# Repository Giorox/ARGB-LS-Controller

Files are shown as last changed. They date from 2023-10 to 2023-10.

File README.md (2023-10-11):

# ARGB-LS-Controller
Circuit diagram, PCB layout and code for an ATTiny85 powered, addressable RGB LED strip controller.

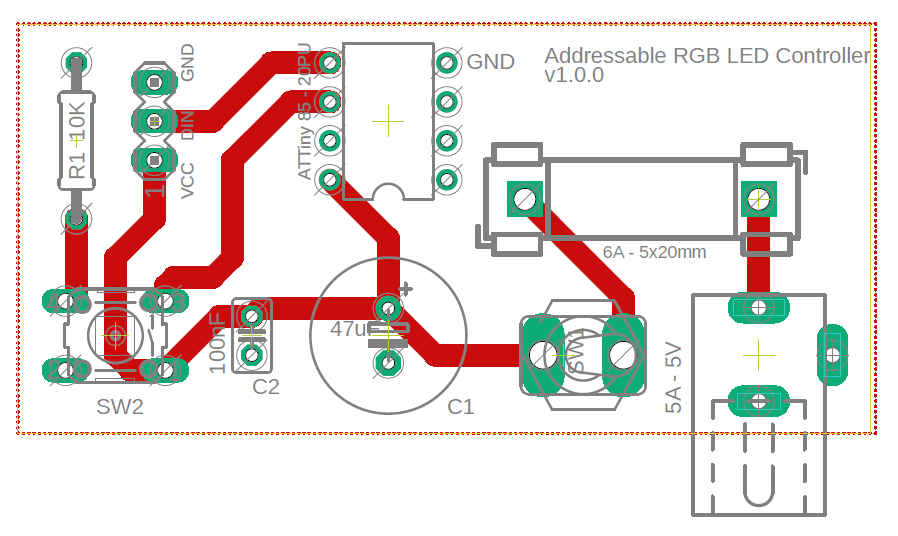
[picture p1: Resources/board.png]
board


# Repository organization

The circuit and board were developed using AutoDesk EAGLE and all files are available in the "Hardware files" folder. Schematic and Board layout PDFs can be found in the "Resources" folder. Controller code can be found in the "Code" folder.

# Project Requirements and Design

The PCB was developed to control any addressable RGB LED strip that uses WS2812B or similar LEDs that take 3 inputs (VCC, GND and Data/DIN) using any DIP8 packaged microcontroller.

All board traces are spec'd to handle up to 5A of current for PCBs fabricated at 1.6mm thickness and 1oz/mm2 allowing for LED strips of up to 88 LED long strips.

Circuit is current-protected up to 6A through a glass fuse at power input and power signal is conditioned using both input capacitors.

R1 is a pull-down resistor for the momentary SW2 push-button that allows for additional inputs to the microcontroller.

The board was developed to handle led-strip control through an ATTiny85 in the DIP8 packaging but should be compatible with all ATTiny microcontrollers in the same outer packaging.

All components are through-hole to reduce cost and facilitate construction.

# Bill of Materials

Besides the board and the led strip:

- 10K ohm resistor (Count: 1)
- 47uF electrolytic capacitor (Count: 1)
- 100nF ceramic capacitor (Count: 1)
- ATTiny85-20PU in DIP8 (Count: 1)
- 6A strand-glass fuse and support (Count: 1)
- Normally-open 4 terminal momentary push-button (Count: 1)
- 5.5mm barrel jack socket (Count: 1)
- SPST switch - Optional (Count: 1)
- DIP8 socket - Optional (Count: 1)

# Quirks

Version 1.0.0 of the board layout/schematic has improper pitch width for the 3 vias used for signal output to the led strip to be used as terminal bars. Pitch between terminals of the fuse are also non-standard, might require customization.

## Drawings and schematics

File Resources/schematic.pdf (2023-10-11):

A

A

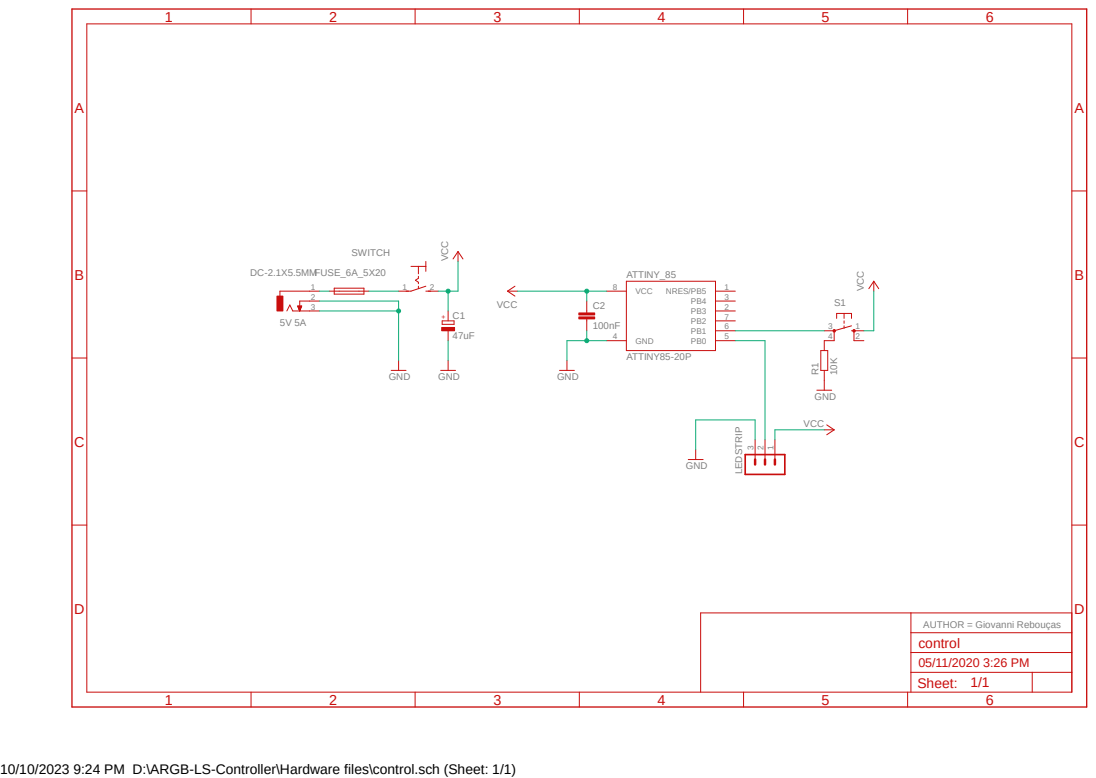
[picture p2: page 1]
GND; ATTINY85-20P; GND¹⁰K; GND VCC; VCC; NRES/PB5; 1 VCC 8; GND 4 ATTINY_85; 1 LEDSTRIP; 1 2 SWITCH; FUSE_6A_5X20

AUTHOR = Giovanni Rebouças
control
Sheet:

10/10/2023 9:24 PM D:\ARGB-LS-Controller\Hardware files\control.sch (Sheet: 1/1)

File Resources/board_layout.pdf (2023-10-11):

6A - 5x20mm R¹ | ATTiny 85 ⁻ 20PU
SW2 | SW¹ ¹⁰K | 100nF | 47uF | 5A ⁻ ⁵V

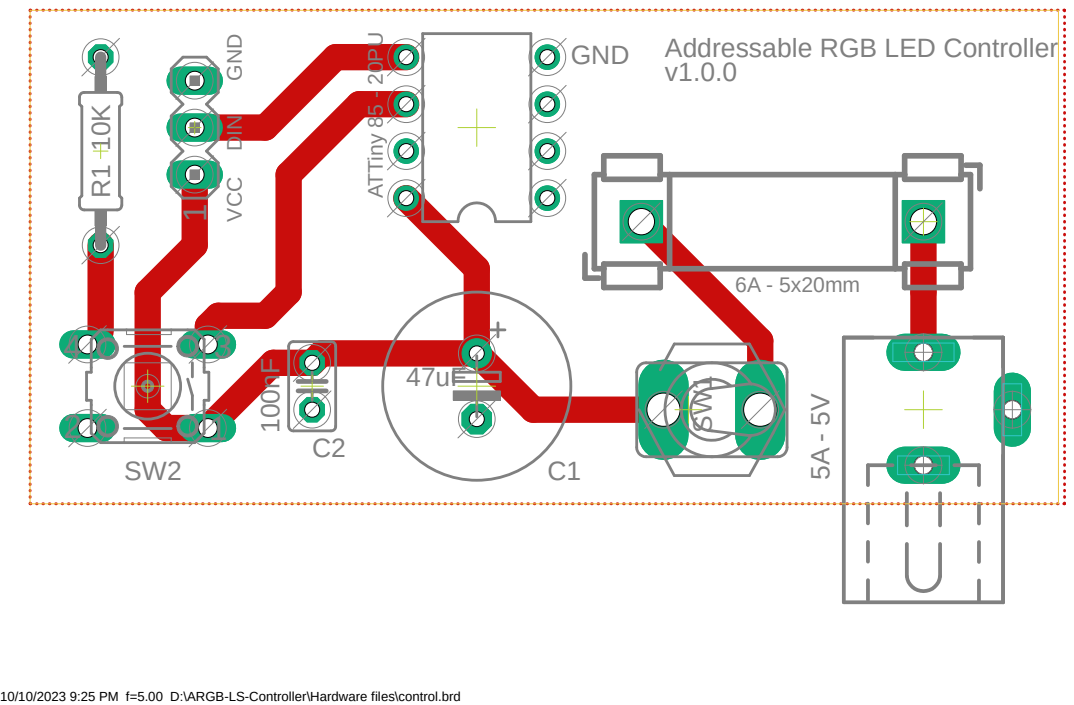
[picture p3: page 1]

10/10/2023 9:25 PM f=5.00 D:\ARGB-LS-Controller\Hardware files\control.brd GND VCC DIN

GND Addressable RGB LED Controller

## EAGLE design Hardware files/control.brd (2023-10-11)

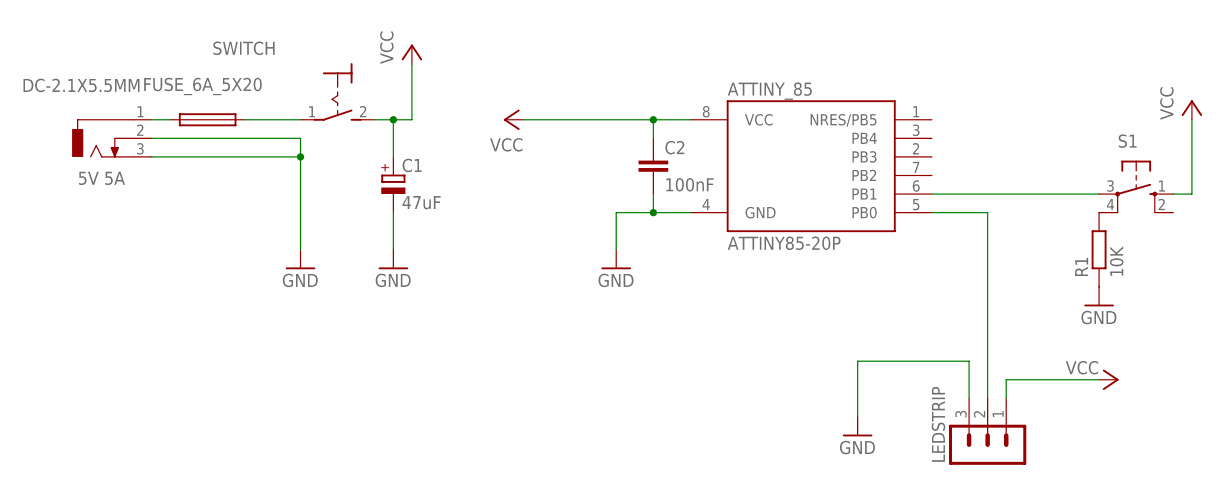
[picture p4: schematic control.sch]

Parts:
ATTINY_85: ATTINY85-20P; PDIP08_300MIL
C1: 47uF; E3,5-10
C2: 100nF; C025-025X050
DC-2.1X5.5MM: 5V 5A; DCJ0303
FUSE_6A_5X20: FUSEBLANK_5X20MM; FUSE_HOLDER_5X20MM
LEDSTRIP: MA03-1
R1: 10K; 0207/10
S1: 10-XX; B3F-10XX
SWITCH: MS243

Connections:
DATAIN: ATTINY_85.5 (PB0), LEDSTRIP.2
GND: ATTINY_85.4 (GND), C1.-, C2.2, DC-2.1X5.5MM.2, DC-2.1X5.5MM.3, LEDSTRIP.3, R1.1
unnamed: R1.2, S1.4 (P1)
unnamed: DC-2.1X5.5MM.1, FUSE_6A_5X20.1
unnamed: FUSE_6A_5X20.2, SWITCH.1
SWITCHIN: ATTINY_85.6 (PB1), S1.3
VCC: ATTINY_85.8 (VCC), C1.+, C2.1, LEDSTRIP.1, S1.1 (S), SWITCH.2 (S)

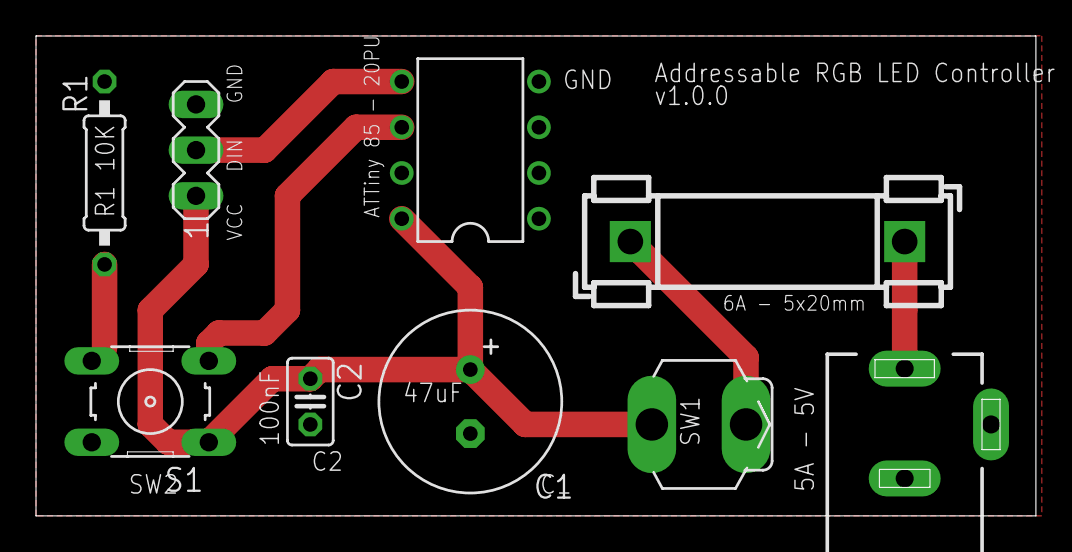
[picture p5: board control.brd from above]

Board: 2 copper layers, 55.5 x 26.7 mm, 9 parts (0 on the bottom side), 7 nets.

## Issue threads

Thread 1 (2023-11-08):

[change request/suggestion]: Embrace USB-C

rafaellehmkuhl, 2023-11-08:
First of all, nice project my friend!

Second of all, I suggest embracing the future and using USB-C for the power socket

Giorox, 2023-11-08:
Good suggestion.

As the circuit requires 5 volts to operate, and each led in the led strip has to be driven by a minimum of 16mA each for full range of the RGB spectrum (256 values across all 3 colors) we could implement standard USB-C which handles 5V up to 15W, allowing a full 3A of current with relative ease.

If we want to have 5V-5A on this board (as it was intended to handle), we'd have to implemente the PD power only spec portion of USB-C which requires some specialized controllers.

I'll leave this issue up to discuss suggestions on implementation!

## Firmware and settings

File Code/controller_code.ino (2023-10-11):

#include <Adafruit_NeoPixel.h>
#ifdef __AVR__
  #include <avr/power.h>
#endif

// Which pin on the arduino is connected to the DIN pin on the LED strip?
#define DATA_PIN 0

// Which pin on the arduino is wired to the momentary push button?
#define BUTTON_PIN 1

// Define the amount of templates/modes available
#define TEMPLATE_COUNT 13

// How many LEDs are on the strip attached to the Arduino?
#define NUMPIXELS 80

// NeoPixel Library setup by instantiating a NeoPixel strip object called pixels
Adafruit_NeoPixel strip(NUMPIXELS, DATA_PIN, NEO_GRB + NEO_KHZ800);

// Mode control variables
boolean oldState = LOW; // Variable used to store previous state
short mode = 0; // Current mode

// Define colors
uint32_t WHITE = strip.Color(255, 255, 255);
uint32_t BLUE = strip.Color(0, 0, 255);
uint32_t RED = strip.Color(255, 0, 0);
uint32_t VIOLET = strip.Color(148, 0, 211);

// Function headers
void colorWipe(uint32_t, int, float=1);

void setup() 
{
  // Code for 16MHz controllers such as the ATTiny85
  //#if defined(__AVR_ATtiny85__) && (F_CPU == 16000000)
  //  clock_prescale_set(clock_div_1);
  //#endif

  pinMode(BUTTON_PIN, INPUT); // Set BUTTON_PIN to input
  pinMode(DATA_PIN, OUTPUT); // Set DATA_PIN to output

  strip.begin(); // INITIALIZE NeoPixel strip object
  strip.show();  // Initialize all pixels to 'off'
  strip.clear();
}

void loop() 
{
  // Get current button state.
  boolean newState = digitalRead(BUTTON_PIN);

  // Check if state changed from low to high (button press).
  if((newState == HIGH) && (oldState == LOW))
  {
    // Short delay to debounce button.
    delay(60);
    // Check if button is still high after debounce.
    newState = digitalRead(BUTTON_PIN);

    if(newState == HIGH)
    {
      // Advance to next mode, wrap around after TEMPLATE_COUNT - 1
      if(++mode > (TEMPLATE_COUNT - 1))
        mode = 0;

      switch(mode)
      {
        case 0:
          colorWipe(strip.Color(0, 0, 0), 0);    // Black/off
          break;
        case 1:
          colorWipe(WHITE, 0); // White
          break;
        case 2:
          colorWipe(WHITE, 0, 0.5); // White, half intensity
          break;
        case 3:
          colorWipe(WHITE, 0, 0.25); // White, quarter intensity
          break;
        case 4:
          colorWipe(VIOLET, 0);
          break;
        case 5:
          colorWipe(VIOLET, 0, 0.5);
          break;
        case 6:
          colorWipe(VIOLET, 0, 0.25);
          break;
        case 7:
          colorWipe(RED, 0);
          break;
        case 8:
          colorWipe(RED, 0, 0.5);
          break;
        case 9:
          colorWipe(RED, 0, 0.25);
          break;
        case 10:
          colorWipe(BLUE, 0);
          break;
        case 11:
          colorWipe(BLUE, 0, 0.5);
          break;
        case 12:
          colorWipe(BLUE, 0, 0.25);
          break;
      }
    }
  }

  // Set the last-read button state to the old state.
  oldState = newState;
}

// Fill strip pixels one after another with a color. Strip is NOT cleared
// first; anything there will be covered pixel by pixel. Pass in color
// (as a single 'packed' 32-bit value, which you can get by calling
// strip.Color(red, green, blue) as shown in the loop() function above),
// and a delay time (in milliseconds) between pixels.
void colorWipe(uint32_t color, int wait, float intensity=1) 
{
  // First, clear the strip
  strip.clear();

  // Get the color composition in RGB
  uint8_t redComp = (color >> 16) & 0xFF;
  uint8_t greenComp = (color >> 8) & 0xFF;
  uint8_t blueComp = color & 0xFF;

  // Apply intensity to desired color
  redComp = redComp*intensity;
  greenComp = greenComp*intensity;
  blueComp = blueComp*intensity;

  // Remake color
  color = strip.Color(redComp, greenComp, blueComp);

  // For each pixel in strip...
  for(short i=0; i<strip.numPixels(); i++) 
  {
    strip.setPixelColor(i, color);         //  Set pixel's color (in RAM)
    strip.show();                          //  Update strip to match
    delay(wait);                           //  Pause for a moment
  }
}

void plantAmbientColor()
{
  // First, clear the strip
  strip.clear();

  // Set smaller color order array's size
  short arraySize = 8;

  // Smallest color order
  // This is the order in which colors will appear in the smallest subset of our leds, which, because of the 1/2, 1/3 e 1/6 proportions, the smallest is 6 leds
  uint32_t colors_array[arraySize] = {WHITE, RED, WHITE, RED, WHITE, BLUE, WHITE, BLUE};

  // Current color
  short colorIndex = 0;

  // For each N pixels in strip according to proportion
  for(short i=0; i<strip.numPixels(); i++) 
  {
     strip.setPixelColor(i, colors_array[colorIndex]);         //  Set pixel's color (in RAM)
     strip.show();                          //  Update strip to match

     if(++colorIndex > arraySize-1)
        colorIndex = 0;
  }
}
